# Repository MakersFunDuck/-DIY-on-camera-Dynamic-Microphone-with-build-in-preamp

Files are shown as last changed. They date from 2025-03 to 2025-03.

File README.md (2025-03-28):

# DIY on-camera Dynamic micrcophone with build-in preamp

This project is a dynamic microphone utilizing a cloned SM57 capsule. The circuit incorporates a THAT 1510 preamp and is powered by phantom power from the XLR input. It is also compatible with dynamic microphones that require phantom power. If you wish to use it this way, simply cut the solder bridges and connect the appropriate ones. Additionally, I’ve left two pins available in case you prefer to power the circuit externally (e.g., with a battery). You can adjust the gain using the onboard knob.
Preview preview

Capsule which I used :
https://s.click.aliexpress.com/e/_omLsn6Z

Microphone Foam
https://s.click.aliexpress.com/e/_oEmwhu5

## License

 See the [LICENSE](LICENSE) file for details.

inspired from : https://github.com/ojg/thatmicpre

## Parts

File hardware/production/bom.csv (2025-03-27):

Designator | Footprint | Quantity | Value | LCSC Part #
C1, C2 | 0805 | 2 | 470p
C10, C12, C7, C8 | C_Elec_10x10.2 | 4 | 220u-50V
C11, C14, C16, C19 | CP_Elec_8x10.5 | 4 | 47u-50V
C13, C18 | C_Elec_10x10.2 | 2 | 1000u-25V
C15, C17, C9 | 0603 | 3 | 10n
C3 | 0805 | 1 | 47p
C4, C5 | CP_Elec_8x5.4 | 2 | 47u-10V-BP
C6 | 0805 | 1 | 100n
D1, D2, D3, D4, D7 | D_SMA_Handsoldering | 5 | FM4004W-W
D10, D14 | 0402 | 2 | LED
D11, D13, D18, D19, D5, D6, D8, D9 | D_SOD-123F | 8 | 1N4148W
D15, D16 | D_SOD-323 | 2 | 10V
D17 | D_SOD-323 | 1 | 18V
F1 | 1206 | 1 | Polyfuse
J1, J2 | PinHeader_1x02_P2.54mm_Vertical | 2 | Conn_01x02_Pin
J3 | Jack_XLR_Neutrik_NC3MBH-0_Horizontal | 1 | NC3MBH1
J4 | Jack_XLR_Neutrik_NC3MBH-1_Horizontal | 1 | NC3FBH1
JP1, JP2, JP3, JP4 | SolderJumper-3_P1.3mm_Bridged12_RoundedPad1.0x1.5mm_NumberLabels | 4 | SolderJumper_3_Bridged12
L1, L2 | 0402 | 2 | 1.2μH
Q1, Q2 | SOT-23-3 | 2 | BC846BLT1G
R1, R2 | 0402 | 2 | 1k2-0.1%
R10, R7 | 0402 | 2 | 22k
R11, R12 | 0402 | 2 | 1.5k
R13, R27, R30, R9 | 0402 | 4 | 10k
R25 | 0402 | 1 | 10R
R26, R29 | 0402 | 2 | 100R
R28 | 0402 | 1 | 4k7
R3, R4 | 0402 | 2 | 10R-1W
R41, R42 | 0402 | 2 | 47R-1W
R5, R6 | 0402 | 2 | 6k8-0.1%-0.5W
R8 | 0402 | 1 | 47k
RV1 | Potentiometer_Vishay_T73XW_Horizontal | 1 | PTN091-H11115DA
U3 | SOIC-8W_5.3x5.3mm_P1.27mm | 1 | 1510S08-U

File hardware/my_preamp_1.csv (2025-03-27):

Reference | Value | Datasheet | Footprint | Qty | DNP | Mfr Part Nr | Description
C1,C2 | 470p | ~ | Capacitor_SMD:C_0805_2012Metric_Pad1.18x1.45mm_HandSolder | 2 |  | ECH-U1H471GX5
C3 | 47p | ~ | Capacitor_SMD:C_0805_2012Metric_Pad1.18x1.45mm_HandSolder | 1 |  | C0805C470J5GAC7210
C4,C5 | 47u-10V-BP | ~ | Capacitor_SMD:CP_Elec_8x5.4 | 2 |  | UWP1A470MCL1GB
C6 | 100n | ~ | Capacitor_SMD:C_0805_2012Metric_Pad1.18x1.45mm_HandSolder | 1 |  | KGF21BR71H104KT
C7,C8,C10,C12 | 220u-50V | ~ | Capacitor_SMD:C_Elec_10x10.2 | 4 |  | 865080657018
C9,C15,C17 | 10n | ~ | Capacitor_SMD:C_0603_1608Metric_Pad1.08x0.95mm_HandSolder | 3 |  | CC0603MRY5V9BB103
C11,C14,C16,C19 | 47u-50V | ~ | Capacitor_SMD:CP_Elec_8x10.5 | 4 |  | ATB476M063
C13,C18 | 1000u-25V | ~ | Capacitor_SMD:C_Elec_10x10.2 | 2 |  | EEE-FT1E102UL
D1,D2,D3,D4,D7 | FM4004W-W | ~ | Diode_SMD:D_SMA_Handsoldering | 5 |  | FM4004W-W
D5,D6,D8,D9,D11,D13,D18,D19 | 1N4148W | ~ | Diode_SMD:D_SOD-123F | 8 |  | 1N4148W
D10,D14 | LED | ~ | LED_SMD:LED_0402_1005Metric_Pad0.77x0.64mm_HandSolder | 2 |  | SML-P12YTT86RR
D15,D16 | 10V | ~ | Diode_SMD:D_SOD-323 | 2 |  | BZX384-B10-QX
D17 | 18V | ~ | Diode_SMD:D_SOD-323 | 1 |  | SZMM3Z18VT1G
F1 | Polyfuse | ~ | Fuse:Fuse_1206_3216Metric_Pad1.42x1.75mm_HandSolder | 1 |  | PTS120660V005
J1,J2 | Conn_01x02_Pin | ~ | Connector_PinHeader_2.54mm:PinHeader_1x02_P2.54mm_Vertical | 2 |  |  | Generic connector, single row, 01x02, script generated
J3 | NC3MBH1 | ~ | Connector_Audio:Jack_XLR_Neutrik_NC3MBH-0_Horizontal | 1 |  | NC3MBH
J4 | NC3FBH1 | ~ | Connector_Audio:Jack_XLR_Neutrik_NC3MBH-1_Horizontal | 1 |  | NC3FBH1
JP1,JP2,JP3,JP4 | SolderJumper_3_Bridged12 | ~ | Jumper:SolderJumper-3_P1.3mm_Bridged12_RoundedPad1.0x1.5mm_NumberLabels | 4 |  |  | 3-pole Solder Jumper, pins 1+2 closed/bridged
L1,L2 | 1.2μH | ~ | Inductor_SMD:L_0402_1005Metric_Pad0.77x0.64mm_HandSolder | 2 |  | MLF1005G1R2JTD25 | -- mixed values --
Q1,Q2 | BC846BLT1G | ~ | Package_TO_SOT_SMD:SOT-23-3 | 2 |  | BC846BLT1G
R1,R2 | 1k2-0.1% | ~ | Resistor_SMD:R_0402_1005Metric_Pad0.72x0.64mm_HandSolder | 2 |  | RT0402BRD071K21L
R3,R4 | 10R-1W | ~ | Resistor_SMD:R_0402_1005Metric_Pad0.72x0.64mm_HandSolder | 2 |  | RT0402BRD0710RL
R5,R6 | 6k8-0.1%-0.5W | ~ | Resistor_SMD:R_0402_1005Metric_Pad0.72x0.64mm_HandSolder | 2 |  | RT0402BRD076K81L
R7,R10 | 22k | ~ | Resistor_SMD:R_0402_1005Metric_Pad0.72x0.64mm_HandSolder | 2 |  | RE0402DRE0722KL
R8 | 47k | ~ | Resistor_SMD:R_0402_1005Metric_Pad0.72x0.64mm_HandSolder | 1 |  | RT0402FRE0747KL
R9,R13,R27,R30 | 10k | ~ | Resistor_SMD:R_0402_1005Metric_Pad0.72x0.64mm_HandSolder | 4 |  | RP0402BRD0747KL
R11,R12 | 1.5k | ~ | Resistor_SMD:R_0402_1005Metric_Pad0.72x0.64mm_HandSolder | 2 |  | RT1206BRD071K5L
R25 | 10R | ~ | Resistor_SMD:R_0402_1005Metric_Pad0.72x0.64mm_HandSolder | 1 |  | RT0402BRD0710RL
R26,R29 | 100R | ~ | Resistor_SMD:R_0402_1005Metric_Pad0.72x0.64mm_HandSolder | 2 |  | RP0402BRD07100RL
R28 | 4k7 | ~ | Resistor_SMD:R_0402_1005Metric_Pad0.72x0.64mm_HandSolder | 1 |  | RP0402BRD074K7L
R41,R42 | 47R-1W | ~ | Resistor_SMD:R_0402_1005Metric_Pad0.72x0.64mm_HandSolder | 2 |  | RT0402BRD0747R5L
RV1 | PTN091-H11115DA | ~ | Potentiometer_THT:Potentiometer_Vishay_T73XW_Horizontal | 1 |  | PTN091-H11115DA | PTN091-H11115DA
U3 | 1510S08-U |  | Package_SO:SOIC-8W_5.3x5.3mm_P1.27mm | 1 |  | 1510S08-U

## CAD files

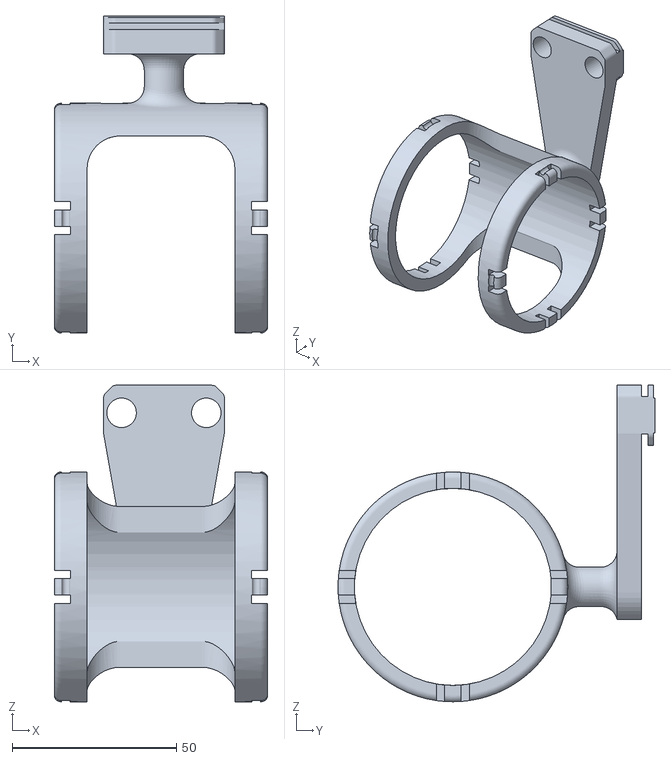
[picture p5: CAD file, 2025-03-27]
3d-models/micholder.STL
65.0 x 96.6 x 96.4

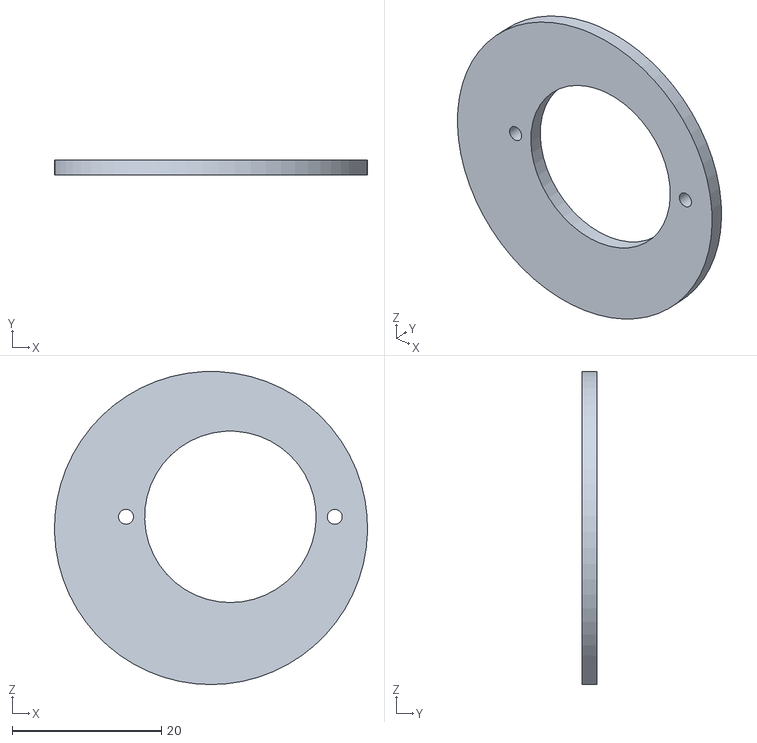
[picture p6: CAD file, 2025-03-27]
3d-models/bottom_plate - bottom_plate-1.STL
42.0 x 2.00 x 42.0

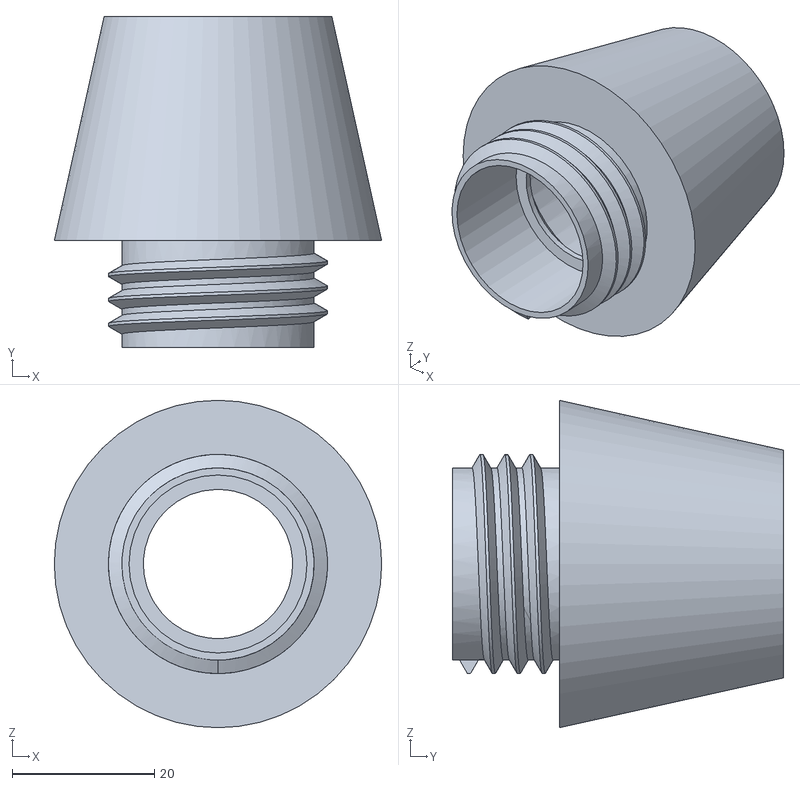
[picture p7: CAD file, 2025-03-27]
3d-models/bottom_plate - capsule holder-1.STL
46.0 x 46.5 x 46.0

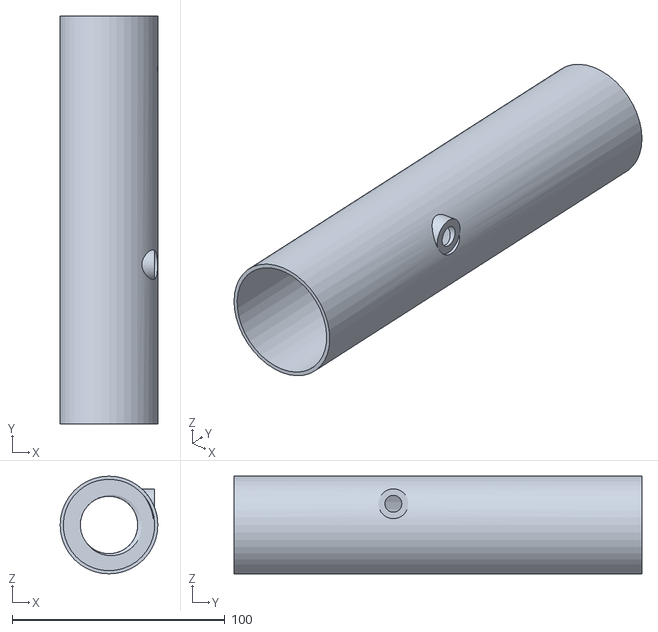
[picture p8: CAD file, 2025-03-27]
3d-models/bottom_plate - bottom-1.STL
46.0 x 192.0 x 46.0

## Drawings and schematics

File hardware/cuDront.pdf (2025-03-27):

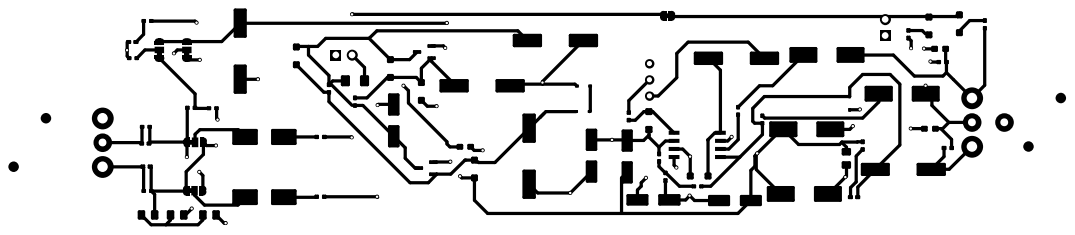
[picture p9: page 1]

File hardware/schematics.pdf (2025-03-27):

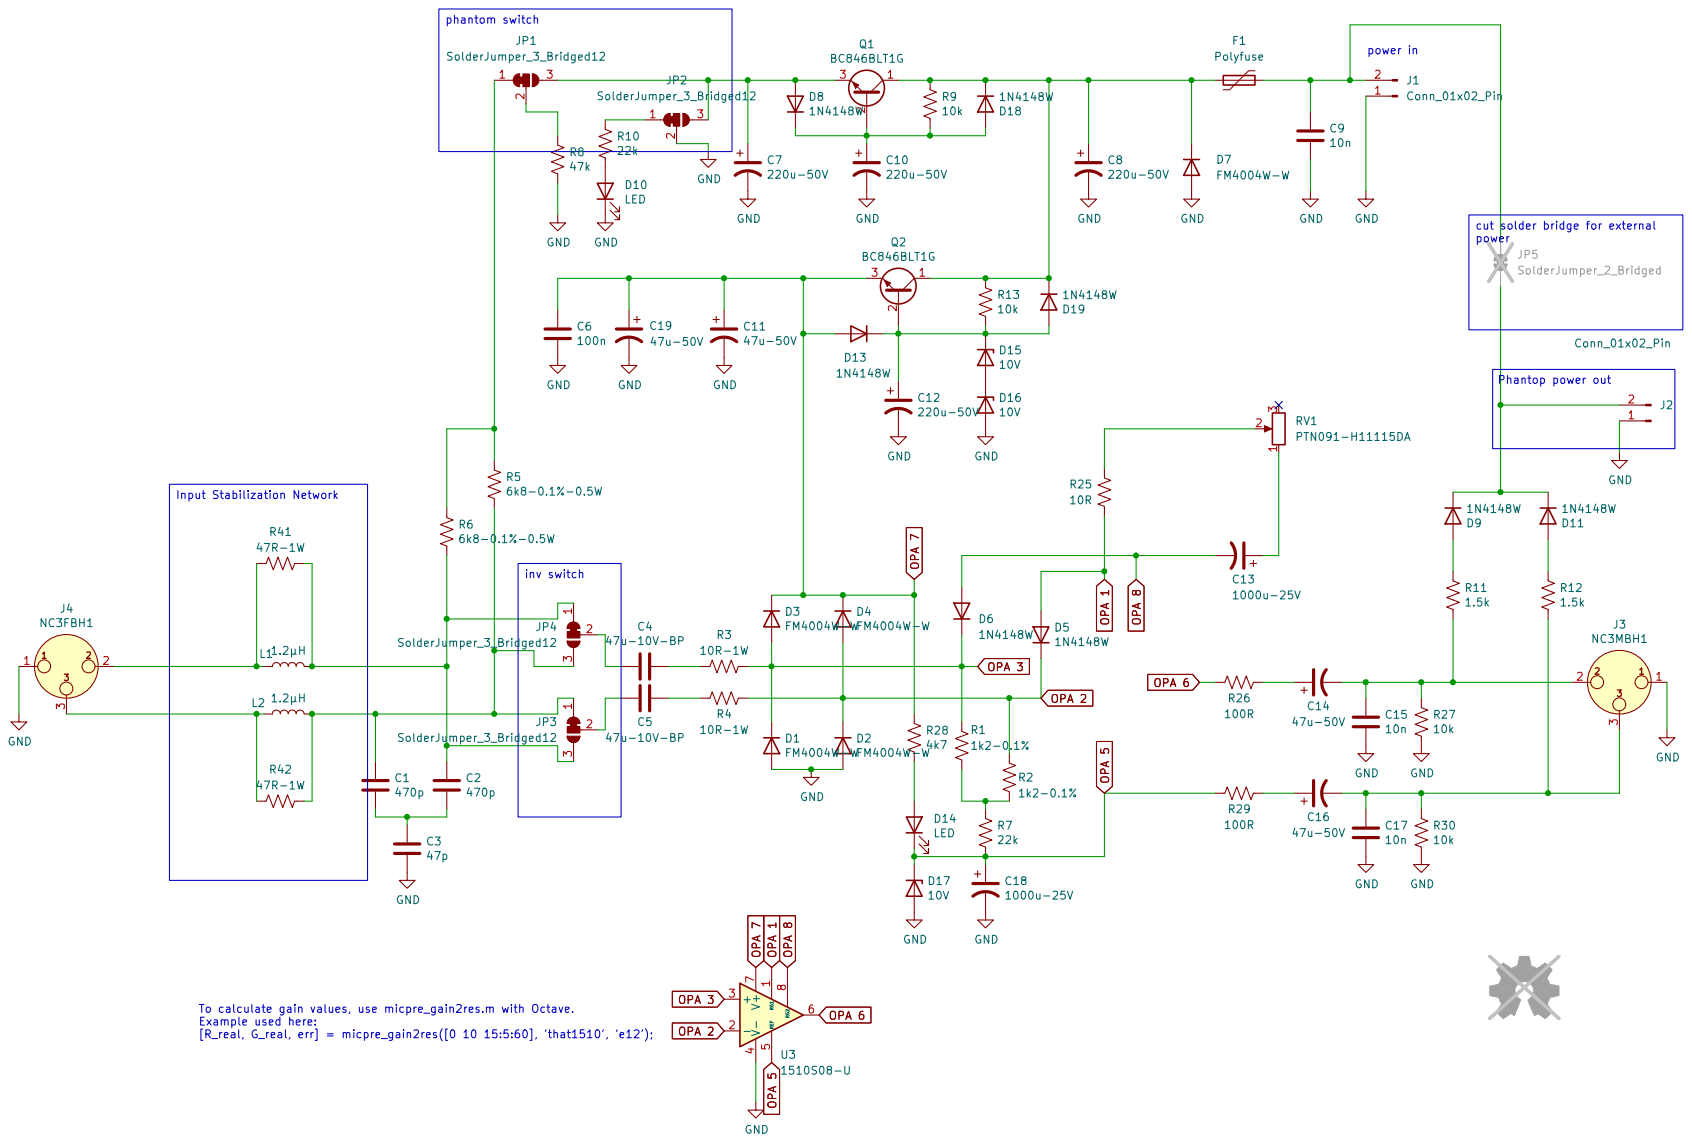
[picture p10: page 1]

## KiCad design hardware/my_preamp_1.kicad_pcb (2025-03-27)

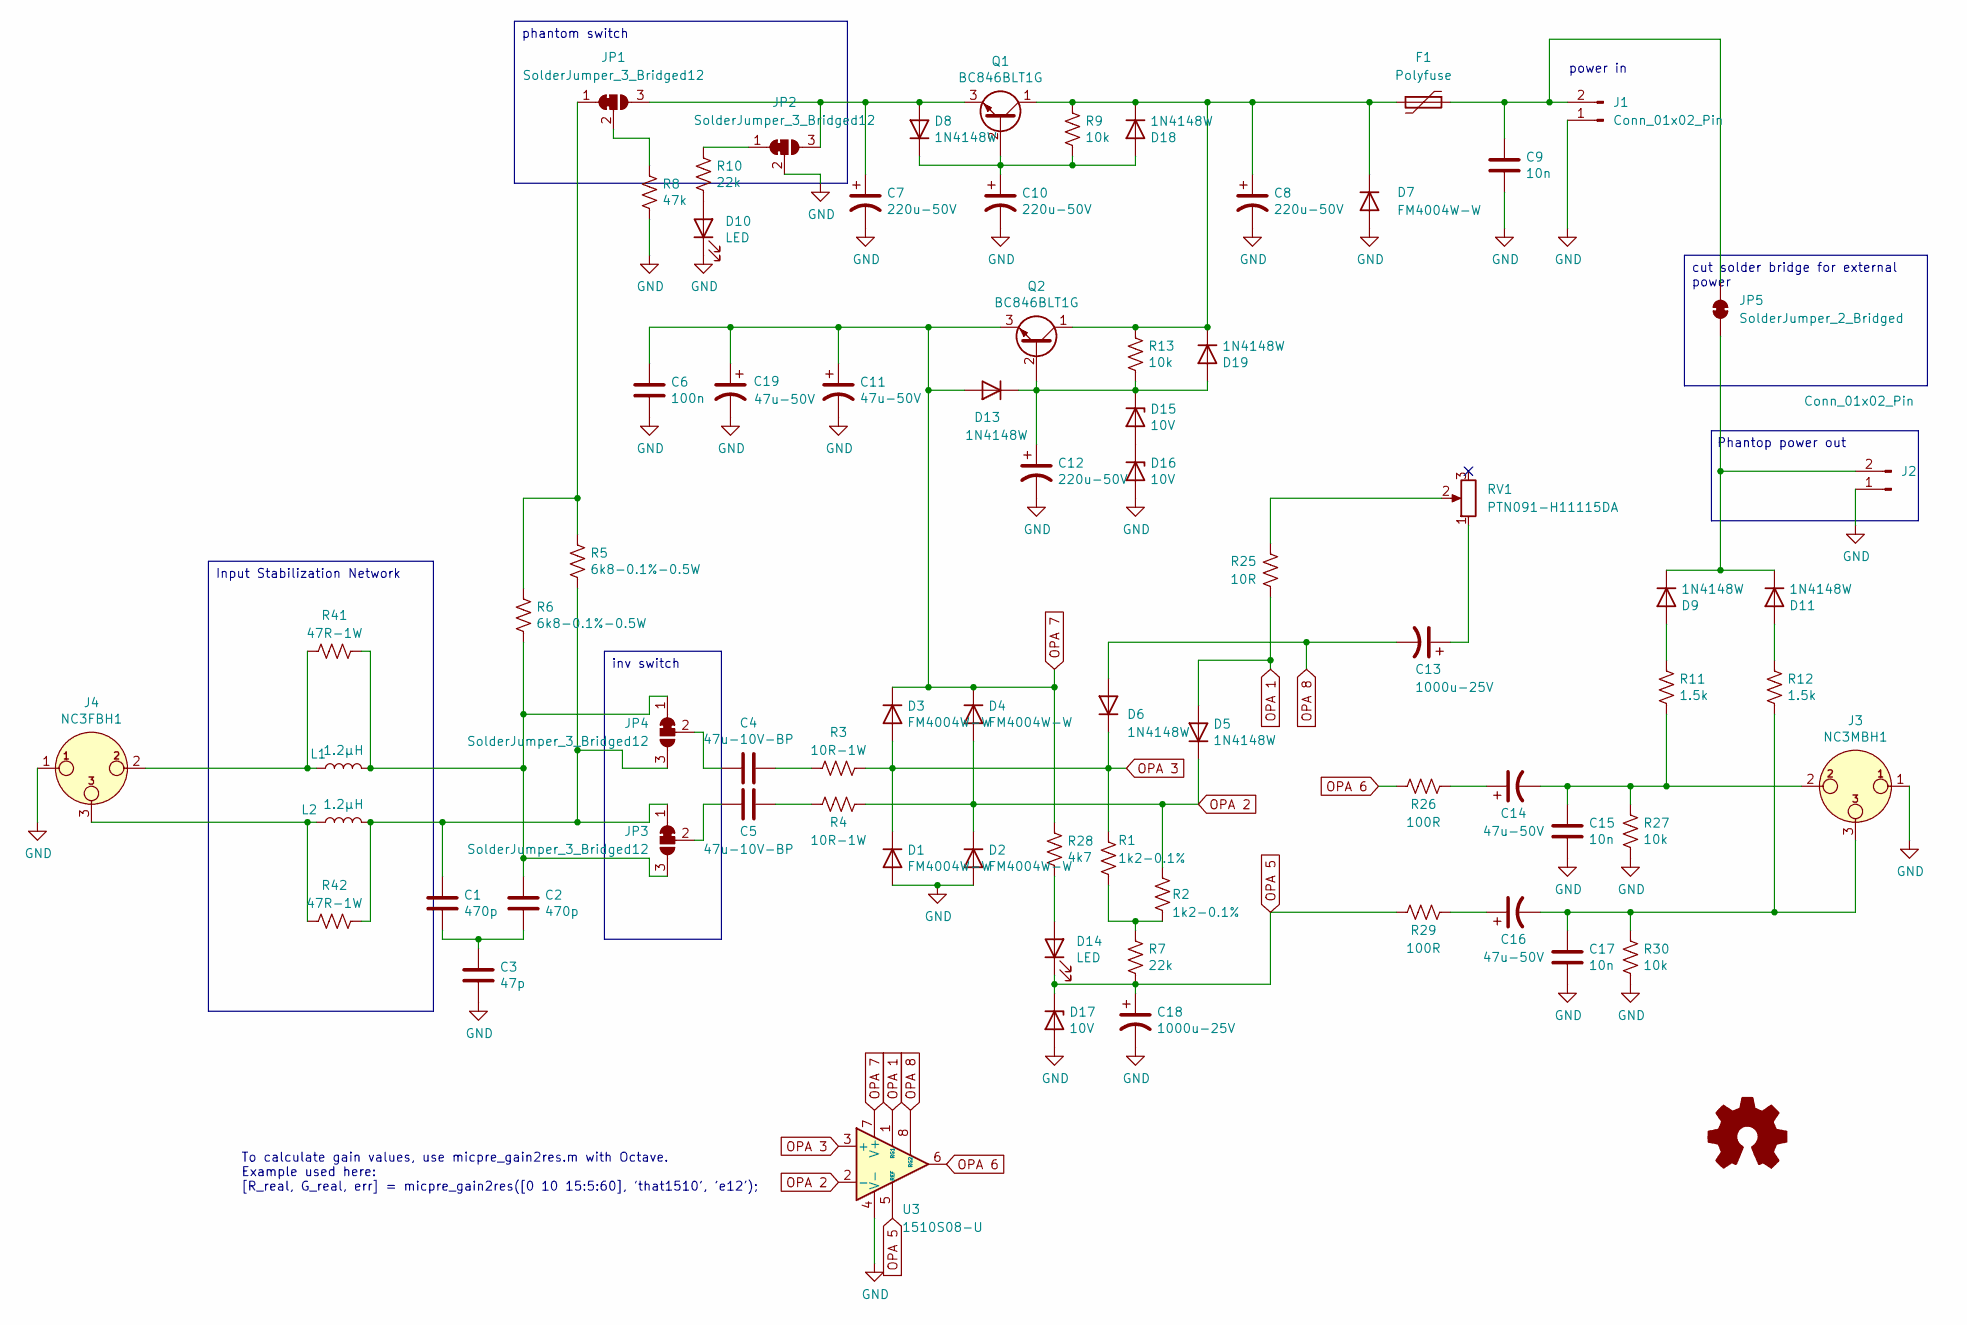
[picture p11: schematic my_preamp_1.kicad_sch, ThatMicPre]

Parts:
C1, C2: 470p; C_0805_2012Metric_Pad1.18x1.45mm_HandSolder; Mfr Part Nr ECH-U1H471GX5
C3: 47p; C_0805_2012Metric_Pad1.18x1.45mm_HandSolder; Mfr Part Nr C0805C470J5GAC7210
C4, C5: 47u-10V-BP; CP_Elec_8x5.4; Mfr Part Nr UWP1A470MCL1GB
C6: 100n; C_0805_2012Metric_Pad1.18x1.45mm_HandSolder; Mfr Part Nr KGF21BR71H104KT
C7, C8, C10, C12: 220u-50V; C_Elec_10x10.2; Mfr Part Nr 865080657018
C9, C15, C17: 10n; C_0603_1608Metric_Pad1.08x0.95mm_HandSolder; Mfr Part Nr CC0603MRY5V9BB103
C11, C14, C16, C19: 47u-50V; CP_Elec_8x10.5; Mfr Part Nr ATB476M063
C13, C18: 1000u-25V; C_Elec_10x10.2; Mfr Part Nr EEE-FT1E102UL
D1, D2, D3, D4, D7: FM4004W-W; D_SMA_Handsoldering; Mfr Part Nr FM4004W-W
D5, D6, D8, D9, D11, D13, D18, D19: 1N4148W; D_SOD-123F; Mfr Part Nr 1N4148W
D10, D14: LED; LED_0402_1005Metric_Pad0.77x0.64mm_HandSolder; Mfr Part Nr SML-P12YTT86RR
D15, D16, D17: 10V; D_SOD-323; Mfr Part Nr BZX384-B10-QX
F1: Polyfuse; Fuse_1206_3216Metric_Pad1.42x1.75mm_HandSolder; Mfr Part Nr PTS120660V005
J1, J2: Conn_01x02_Pin; PinHeader_1x02_P2.54mm_Vertical
J3: NC3MBH1; Jack_XLR_Neutrik_NC3MBH-0_Horizontal; Mfr Part Nr NC3MBH
J4: NC3FBH1; Jack_XLR_Neutrik_NC3MAFH-PH_Horizontal; Mfr Part Nr NC3FBH1
JP1, JP2, JP3, JP4: SolderJumper_3_Bridged12; SolderJumper-3_P1.3mm_Bridged12_RoundedPad1.0x1.5mm_NumberL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
JP5: SolderJumper_2_Bridged; SolderJumper-2_P1.3mm_Bridged_RoundedPad1.0x1.5mm
L1, L2: 1.2μH; L_0402_1005Metric_Pad0.77x0.64mm_HandSolder; Mfr Part Nr MLF1005G1R2JTD25
Q1, Q2: BC846BLT1G; SOT-23-3; Mfr Part Nr BC846BLT1G
R1, R2: 1k2-0.1%; R_0402_1005Metric_Pad0.72x0.64mm_HandSolder; Mfr Part Nr RT0402BRD071K21L
R3, R4: 10R-1W; R_0402_1005Metric_Pad0.72x0.64mm_HandSolder; Mfr Part Nr RT0402BRD0710RL
R5, R6: 6k8-0.1%-0.5W; R_0402_1005Metric_Pad0.72x0.64mm_HandSolder; Mfr Part Nr RT0402BRD076K81L
R7, R10: 22k; R_0402_1005Metric_Pad0.72x0.64mm_HandSolder; Mfr Part Nr RE0402DRE0722KL
R8: 47k; R_0402_1005Metric_Pad0.72x0.64mm_HandSolder; Mfr Part Nr RT0402FRE0747KL
R9, R13: 10k; R_0402_1005Metric_Pad0.72x0.64mm_HandSolder; Mfr Part Nr RP0402BRD0747KL
R11, R12: 1.5k; R_0402_1005Metric_Pad0.72x0.64mm_HandSolder; Mfr Part Nr ERA-2APB152X
R25: 10R; R_0402_1005Metric_Pad0.72x0.64mm_HandSolder; Mfr Part Nr RT0402BRD0710RL
R26, R29: 100R; R_0402_1005Metric_Pad0.72x0.64mm_HandSolder; Mfr Part Nr RP0402BRD07100RL
R27, R30: 10k; R_0402_1005Metric_Pad0.72x0.64mm_HandSolder; Mfr Part Nr MCS0402MD1002BE100
R28: 4k7; R_0402_1005Metric_Pad0.72x0.64mm_HandSolder; Mfr Part Nr RP0402BRD074K7L
R41, R42: 47R-1W; R_0402_1005Metric_Pad0.72x0.64mm_HandSolder; Mfr Part Nr RT0402BRD0747R5L
RV1: PTN091-H11115DA; Potentiometer_Vishay_T73XW_Horizontal; Mfr Part Nr PTN091-H11115DA
U3: 1510S08-U; SOIC-8W_5.3x5.3mm_P1.27mm; Mfr Part Nr 1510S08-U

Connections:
GND: C3.2, C6.2, C7.2, C8.2, C9.2, C10.2, C11.2, C12.2, C15.2, C17.2, C18.2, C19.2, D1.2 (A), D2.2 (A), D7.2 (A), D10.1 (K), D16.2 (A), D17.2 (A), J1.1, J2.1, J3.1, J4.1, JP2.2 (C), R8.2, R27.2, R30.2, U3.4 (V-)
unnamed: C1.2, C2.2, C3.1
unnamed: C4.2, R3.2
unnamed: C5.2, R4.2
unnamed: C13.1, RV1.1
unnamed: C14.1, R26.1
unnamed: C14.2, C15.1, J3.2, R11.2, R27.1
unnamed: C16.1, R29.1
unnamed: C16.2, C17.1, J3.3, R12.2, R30.1
unnamed: C7.1, D8.2 (A), JP1.3 (B), JP2.3 (B), Q1.3 (E)
unnamed: D9.2 (A), R11.1
unnamed: D10.2 (A), R10.2
unnamed: D11.2 (A), R12.1
unnamed: D9.1 (K), D11.1 (K), J2.2, JP5.1 (A)
unnamed: C12.1, D13.1 (K), D15.1 (K), D19.2 (A), Q2.2 (B), R13.2
unnamed: D14.2 (A), R28.2
unnamed: D15.2 (A), D16.1 (K)
unnamed: C10.1, D8.1 (K), D18.2 (A), Q1.2 (B), R9.2
unnamed: C8.1, D7.1 (K), D18.1 (K), D19.1 (K), F1.2, Q1.1 (C), Q2.1 (C), R9.1, R13.1
unnamed: C9.1, F1.1, J1.2, JP5.2 (B)
unnamed: J4.2, L1.1, R41.2
unnamed: J4.3, L2.1, R42.2
unnamed: JP1.1 (A), R5.1, R6.1
unnamed: JP1.2 (C), R8.1
unnamed: JP2.1 (A), R10.1
unnamed: C1.1, JP3.1 (A), JP4.3 (B), L2.2, R5.2, R42.1
unnamed: C2.1, JP3.3 (B), JP4.1 (A), L1.2, R6.2, R41.1
unnamed: C5.1, JP3.2 (C)
unnamed: C4.1, JP4.2 (C)
unnamed: R1.2, R2.2, R7.1
unnamed: R25.2, RV1.2
OPA 1: D5.2 (A), R25.1, U3.1 (RG1)
OPA 2: D2.1 (K), D4.2 (A), D5.1 (K), R2.1, R4.1, U3.2 (-)
OPA 3: D1.1 (K), D3.2 (A), D6.1 (K), R1.1, R3.1, U3.3 (+)
OPA 5: C18.1, D14.1 (K), D17.1 (K), R7.2, R29.2, U3.5 (REF)
OPA 6: R26.2, U3.6
OPA 7: C6.1, C11.1, C19.1, D3.1 (K), D4.1 (K), D13.2 (A), Q2.3 (E), R28.1, U3.7 (V+)
OPA 8: C13.2, D6.2 (A), U3.8 (RG2)

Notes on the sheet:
Phantop power out
To calculate gain values, use micpre_gain2res.m with Octave. Example used here: [R_real, G_real, err] = micpre_gain2res([0 10 15:5:60], 'that1510', 'e12');
power in
cut solder bridge for external power
inv switch
Input Stabilization Network
phantom switch

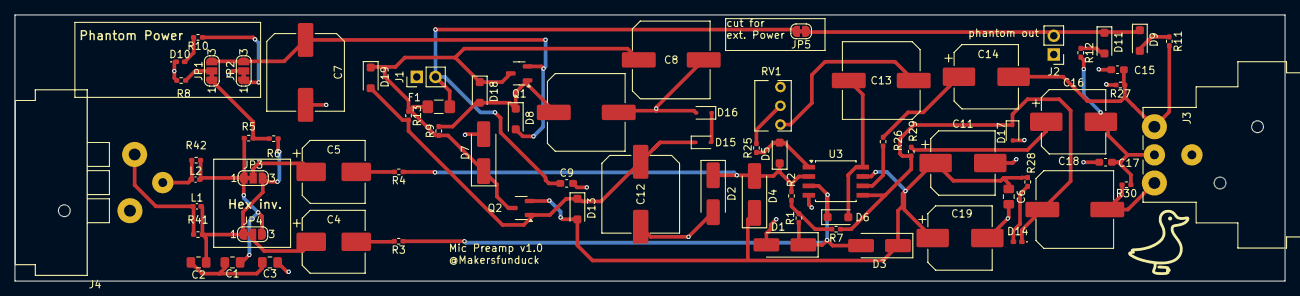
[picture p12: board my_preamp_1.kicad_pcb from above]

Board: 2 copper layers, 172.0 x 36.1 mm, 74 parts (0 on the bottom side), 38 nets.
